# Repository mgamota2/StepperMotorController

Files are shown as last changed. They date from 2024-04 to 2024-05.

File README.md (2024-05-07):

# Stepper Motor Controller

## Purpose

This project was designed for the EV Concept Car team to enable autonomous steering. Stepper motors provide precise rotation and high torque, making them perfect for turning a steering wheel.

## Design

This project is a 48V isolated stepper motor controller which can be controlled over CAN or USB. The MCU used for this project is the STM32F103C8T6. The foundational part of the design are the 2 isolated H-Bridge circuits which drive the two coils in the stepper motor. The PCB files, gerbers, and BOM are included in this repo.

## Sources

Thank you to Nefastor Online for the COM over USB library for the STM32F1:
https://nefastor.com/microcontrollers/stm32/usb/stm32cube-usb-device-library/cdc-continued/
https://github.com/Nefastor-Online/STM32_VCP.git

## Report

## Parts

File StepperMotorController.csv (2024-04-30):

Source: | C:\Users\mggam\Documents\University of Illinois\EV Concept\StepperMotorController\StepperMotorController.kicad_sch
Date: | 2/20/2024 16:06
Tool: | Eeschema (6.0.7)
Generator: | C:\Program Files\KiCad\6.0\bin\scripting\plugins/bom_csv_grouped_by_value_with_fp.py
Component Count: | 132
Ref | Qnty | Value | Cmp name | Footprint | Description | Vendor
C1, C17, | 2 | 470uF | C_Polarized_US | Capacitor_THT:CP_Radial_D16.0mm_P7.50mm | Polarized capacitor, US symbol
C2, C3, C4, C6, C8, C9, C10, C13, C14, C18, C19, C21, C23, C24, C25, C26, C30, C31, | 18 | 0.1uF | C | Capacitor_SMD:C_0805_2012Metric | Unpolarized capacitor
C5, C7, C20, C22, | 4 | 1uF | C | Capacitor_SMD:C_0805_2012Metric | Unpolarized capacitor
C11, C12, C15, C16, C28, C29, C32, C33, | 8 | 4.7uF | C_Polarized_US | Capacitor_THT:CP_Radial_D8.0mm_P5.00mm | Polarized capacitor, US symbol
C27, C35, C36, | 3 | 4.7uF | C | Capacitor_SMD:C_0805_2012Metric | Unpolarized capacitor
C34, C37, C40, C47, | 4 | 10uF | C | Capacitor_SMD:C_0805_2012Metric | Unpolarized capacitor
C38, C39, | 2 | 10pF | C | Capacitor_SMD:C_0603_1608Metric | Unpolarized capacitor
C41, C42, C43, C44, C45, C46, | 6 | .1uF | C | Capacitor_SMD:C_0805_2012Metric | Unpolarized capacitor
CBOOT1, | 1 | 0.1uF | C | Capacitor_SMD:C_0805_2012Metric | Unpolarized capacitor
D1, | 1 | 82400102 | 82400102 | SamacSys_Parts:SOT95P280X145-6N | TVS Diode Array WE-TVS 2-Ch+VDD 5V SOT23 Wurth Elektronik 82400102, Uni-Directional TVS Diode Array Array, 7.7V, 6-Pin SOT-23
D2, D9, D10, D11, D12, D13, D14, | 7 | LED | LED | LED_SMD:LED_0603_1608Metric | Light emitting diode
D4, D5, D6, D7, | 4 | D | D | Diode_SMD:D_0805_2012Metric | Diode
D8, | 1 | D_Zener | D_Zener | Diode_SMD:D_0805_2012Metric | Zener diode
FB1, | 1 | FerriteBead | FerriteBead | Resistor_SMD:R_0805_2012Metric | Ferrite bead
IC1, IC2, IC4, IC5, | 4 | NCP51561BADWR2G | NCP51561BADWR2G | SamacSys_Parts:SOIC127P1030X265-16N | Isolated Gate Drivers 5 kVRMS Isolated Dual Channel 4.5/9 A Gate Driver 4.5/9A Isolated Dual Channel Gate Driver with 8V UVLO and ENABLE
IC3, | 1 | LMR51610XDBVR | LMR51610XDBVR | SamacSys_Parts:SOT95P280X145-6N | Switching Voltage Regulators SIMPLE SWITCHER&reg; 4.5-V to 65-V, 1-A synchronous buck converter with 25-&micro;A&nbsp;IQ 6-SOT-23 -40 to 150
IC6, | 1 | TC1264-3.3VDBTR | TC1264-3.3VDBTR | SamacSys_Parts:SOT230P700X180-4N | LDO Voltage Regulators 800mA Fixed Output
J1, | 1 | USB4085-GF-A_REVA4 | USB4085-GF-A_REVA4 | Connector_USB:USB_C_Receptacle_GCT_USB4085
J2, | 1 | 54602-908LF | 54602-908LF | SamacSys_Parts:54602908LF
J3, | 1 | PDS1-S24-S5-M-TR | PDS1-S24-S5-M-TR | SamacSys_Parts:PDS1S24S5MTR | Module DC-DC 24VIN 1-OUT 5V 0.2A 1W 5-Pin SMD Module T/R
J4, | 1 | Conn_02x05_Odd_Even | Conn_02x05_Odd_Even | Connector_PinSocket_2.54mm:PinSocket_2x05_P2.54mm_Vertical | Generic connector, double row, 02x05, odd/even pin numbering scheme (row 1 odd numbers, row 2 even numbers), script generated (kicad-library-utils/schlib/autogen/connector/)
J5, | 1 | 1984633 | 1984633 | Connector_Phoenix_GMSTB:PhoenixContact_GMSTBVA_2,5_4-G-7,62_1x04_P7.62mm_Vertical
J6, J7, | 2 | 7807 | 7807 | screw:CONN_7807_KEY
L1, | 1 | 82uH | L | Inductor_SMD:L_Bourns_SRR1260 | Inductor
Q1, Q2, Q3, Q4, Q5, Q6, Q7, Q8, | 8 | IRF740 | IRF740 | Package_TO_SOT_THT:TO-220-3_Vertical | 10A Id, 400V Vds, N-Channel Power MOSFET, 500mOhm Rds, TO-220AB
R1, R2, R21, R22, | 4 | 20k | R | Resistor_SMD:R_0805_2012Metric | Resistor
R3, R6, | 2 | 5.11k | R | Resistor_SMD:R_0805_2012Metric | Resistor
R4, R5, R12, R14, R15, R17, R23, R24, R31, R33, R34, R36, | 12 | 10k | R | Resistor_SMD:R_0805_2012Metric | Resistor
R7, | 1 | 120 | R | Resistor_SMD:R_0805_2012Metric | Resistor
R8, R9, R10, R11, R13, R16, R27, R28, R29, R30, R32, R35, | 12 | 10 | R | Resistor_SMD:R_0805_2012Metric | Resistor
R19, R38, R39, R40, R41, R42, R43, | 7 | 300 | R | Resistor_SMD:R_0805_2012Metric | Resistor
R20, | 1 | 1.5k | R | Resistor_SMD:R_0805_2012Metric | Resistor
R25, | 1 | 100k | R | Resistor_SMD:R_0805_2012Metric | Resistor
R26, | 1 | 3.48k | R | Resistor_SMD:R_0805_2012Metric | Resistor
R37, | 1 | 1K | R | Resistor_SMD:R_0805_2012Metric | Resistor
SW1, | 1 | 100SP1T1B4M2QE | 100SP1T1B4M2QE | 100S:100SP1T1_EWI
SW2, | 1 | 1825255-1 | 1825255-1 | switch182:SW3_1825255-1_TEC
SW3, | 1 | SW_Push | SW_Push | Button_Switch_SMD:SW_Push_SPST_NO_Alps_SKRK | Push button switch, generic, two pins
U1, | 1 | ISO1050DUB | ISO1050DUB | Package_SO:SOP-8_6.62x9.15mm_P2.54mm | Isolated CAN Transceiver, SOP-8
U2, | 1 | STM32F103C8Tx | STM32F103C8Tx | Package_QFP:LQFP-48_7x7mm_P0.5mm | ARM Cortex-M3 MCU, 64KB flash, 20KB RAM, 72MHz, 2-3.6V, 37 GPIO, LQFP-48
Y1, | 1 | Crystal_GND24 | Crystal_GND24 | SamacSys_Parts:ECS801033CHNTR3 | Four pin crystal, GND on pins 2 and 4

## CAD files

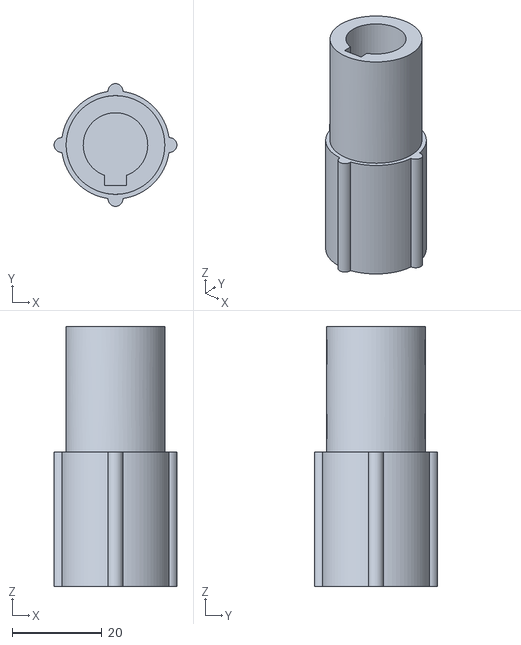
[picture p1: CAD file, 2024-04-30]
ApadterBody.stl
27.4 x 27.4 x 58.0

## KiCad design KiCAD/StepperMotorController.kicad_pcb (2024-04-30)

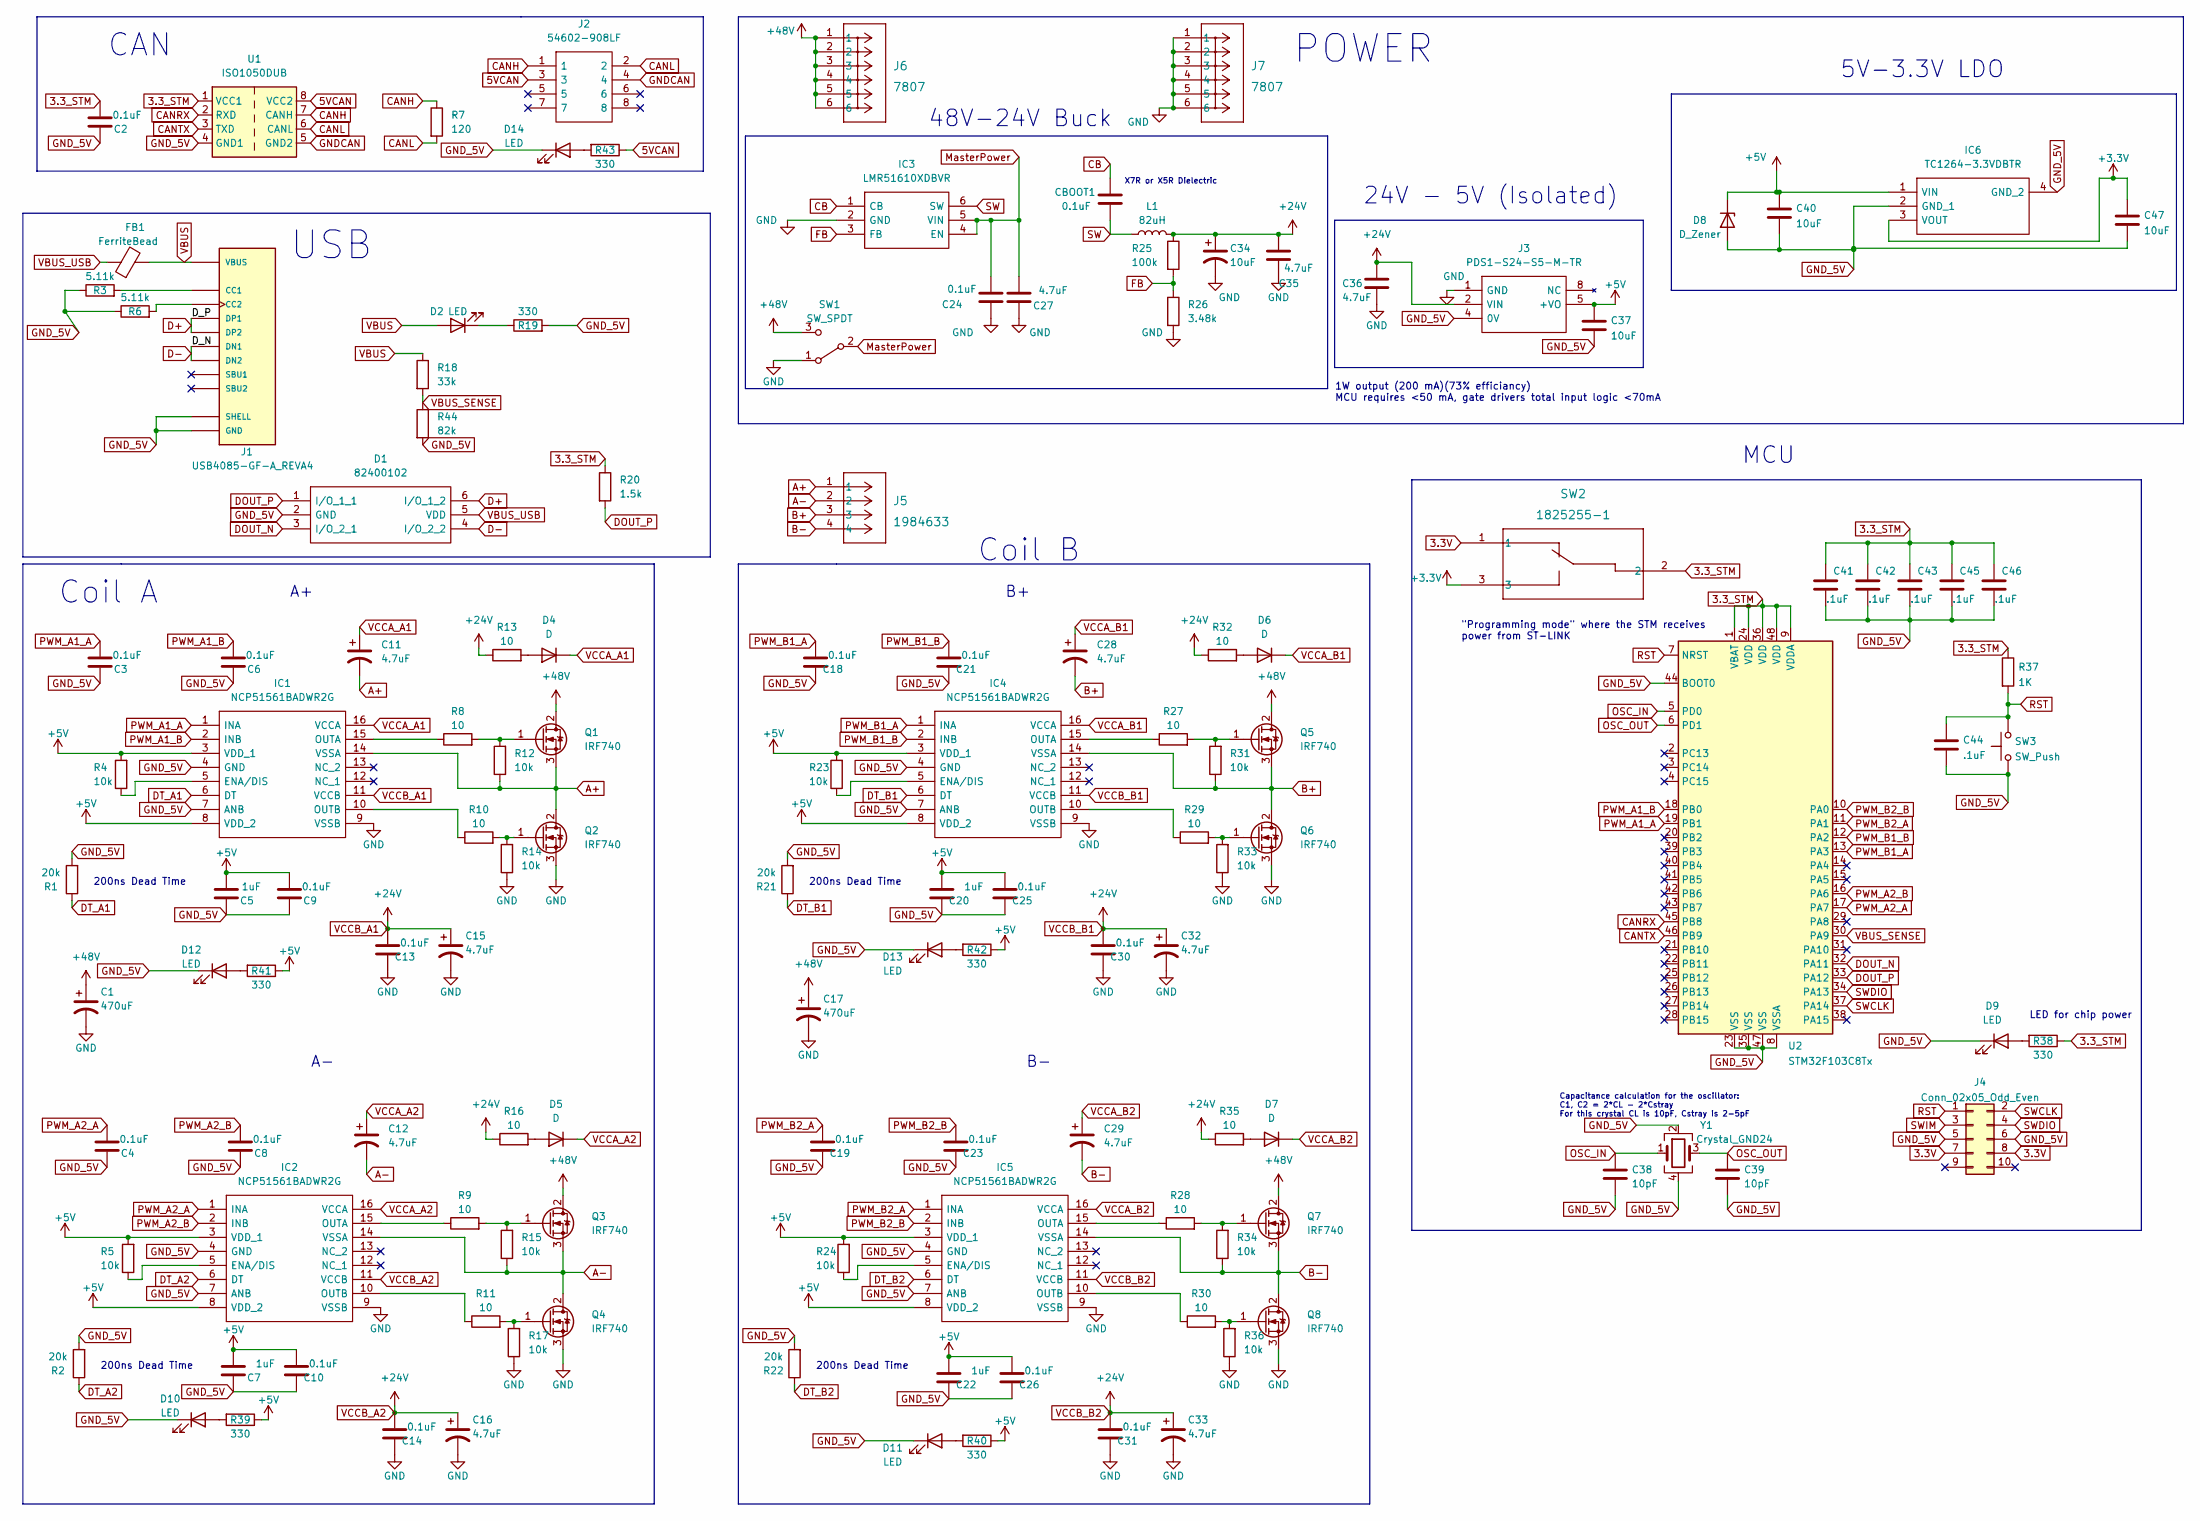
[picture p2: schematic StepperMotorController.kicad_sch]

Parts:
C1, C17: 470uF; CP_Radial_D16.0mm_P7.50mm
C2, C3, C4, C6, C8, C9, C10, C13, C14, C18, C19, C21, C23, C24, C25, C26, C30, C31: 0.1uF; C_0805_2012Metric
C5, C7, C20, C22: 1uF; C_0805_2012Metric
C11, C12, C15, C16, C28, C29, C32, C33: 4.7uF; CP_Radial_D8.0mm_P5.00mm
C27, C35, C36: 4.7uF; C_0805_2012Metric
C34, C37, C40, C47: 10uF; C_0805_2012Metric
C38, C39: 10pF; C_0603_1608Metric
C41, C42, C43, C44, C45, C46: .1uF; C_0805_2012Metric
CBOOT1: 0.1uF; C_0805_2012Metric
D1: 82400102; SOT95P280X145-6N; Mouser Part Number 710-82400102
D2, D9, D10, D11, D12, D13, D14: LED; LED_0603_1608Metric
D4, D5, D6, D7: D; D_0805_2012Metric
D8: D_Zener; D_0805_2012Metric
FB1: FerriteBead; R_0805_2012Metric
IC1, IC2, IC4, IC5: NCP51561BADWR2G; SOIC127P1030X265-16N; Manufacturer_Part_Number NCP51561BADWR2G
IC3: LMR51610XDBVR; SOT95P280X145-6N; Mouser Part Number 595-LMR51610XDBVR
IC6: TC1264-3.3VDBTR; SOT230P700X180-4N; Mouser Part Number 579-TC1264-3.3VDBTR
J1: USB4085-GF-A_REVA4; USB_C_Receptacle_GCT_USB4085; PARTREV A4
J2: 54602-908LF; 54602908LF; Mouser Part Number 649-54602-908LF
J3: PDS1-S24-S5-M-TR; PDS1S24S5MTR; Mouser Part Number 490-PDS1-S24-S5-M-TR
J4: Conn_02x05_Odd_Even; PinSocket_2x05_P2.54mm_Vertical
J5: 1984633; PhoenixContact_GMSTBVA_2,5_4-G-7,62_1x04_P7.62mm_Vertical
J6, J7: 7807; CONN_7807_KEY
L1: 82uH; L_Bourns_SRR1260
Q1, Q2, Q3, Q4, Q5, Q6, Q7, Q8: IRF740; TO-220-3_Vertical
R1, R2, R21, R22: 20k; R_0805_2012Metric
R3, R6: 5.11k; R_0805_2012Metric
R4, R5, R12, R14, R15, R17, R23, R24, R31, R33, R34, R36: 10k; R_0805_2012Metric
R7: 120; R_0805_2012Metric
R8, R9, R10, R11, R13, R16, R27, R28, R29, R30, R32, R35: 10; R_0805_2012Metric
R18: 33k; R_0805_2012Metric
R19, R38, R39, R40, R41, R42, R43: 330; R_0805_2012Metric
R20: 1.5k; R_0805_2012Metric
R25: 100k; R_0805_2012Metric
R26: 3.48k; R_0805_2012Metric
R37: 1K; R_0805_2012Metric
R44: 82k; R_0805_2012Metric
SW1: SW_SPDT; 100SP1T1_EWI
SW2: 1825255-1; SW3_1825255-1_TEC
SW3: SW_Push; SW_Push_SPST_NO_Alps_SKRK
U1: ISO1050DUB; SOP-8_6.62x9.15mm_P2.54mm
U2: STM32F103C8Tx; LQFP-48_7x7mm_P0.5mm
Y1: Crystal_GND24; ECS801033CHNTR3

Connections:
3.3V: J4.7, J4.8, SW2.1
3.3_STM: C2.2, C41.1, C42.1, C43.1, C45.1, C46.1, R20.1, R37.1, R38.1, SW2.2, U1.1 (VCC1), U2.1 (VBAT), U2.9 (VDDA), U2.24 (VDD), U2.36 (VDD), U2.48 (VDD)
5VCAN: J2.3, R43.1, U1.8 (VCC2)
+3.3V: C47.1, IC6.3 (VOUT), SW2.3
+5V: C5.2, C7.2, C9.2, C10.2, C20.2, C22.2, C25.2, C26.2, C37.1, C40.1, D8.1 (K), IC1.3 (VDD_1), IC1.8 (VDD_2), IC2.3 (VDD_1), IC2.8 (VDD_2), IC4.3 (VDD_1), IC4.8 (VDD_2), IC5.3 (VDD_1), IC5.8 (VDD_2), IC6.1 (VIN), J3.5 (+VO), R4.2, R5.2, R23.2, R24.2, R39.1, R40.1, R41.1, R42.1
+48V: C1.1, C17.1, J6.1, J6.2, J6.3, J6.4, J6.5, J6.6, Q1.2 (D), Q3.2 (D), Q5.2 (D), Q7.2 (D), SW1.3 (C)
A+: C11.2, IC1.14 (VSSA), J5.1, Q1.3 (S), Q2.2 (D), R12.1
A-: C12.2, IC2.14 (VSSA), J5.2, Q3.3 (S), Q4.2 (D), R15.1
B+: C28.2, IC4.14 (VSSA), J5.3, Q5.3 (S), Q6.2 (D), R31.1
B-: C29.2, IC5.14 (VSSA), J5.4, Q7.3 (S), Q8.2 (D), R34.1
CANH: J2.1, R7.1, U1.7 (CANH)
CANL: J2.2, R7.2, U1.6 (CANL)
CANRX: U1.2 (RXD), U2.45 (PB8)
CANTX: U1.3 (TXD), U2.46 (PB9)
CB: CBOOT1.1, IC3.1 (CB)
D+: D1.6 (I/O_1_2), J1.A6 (DP1), J1.B6 (DP2)
D-: D1.4 (I/O_2_2), J1.A7 (DN1), J1.B7 (DN2)
DOUT_N: D1.3 (I/O_2_1), U2.32 (PA11)
DOUT_P: D1.1 (I/O_1_1), R20.2, U2.33 (PA12)
DT_A1: IC1.6 (DT), R1.1
DT_A2: IC2.6 (DT), R2.1
DT_B1: IC4.6 (DT), R21.1
DT_B2: IC5.6 (DT), R22.1
FB: IC3.3 (FB), R25.2, R26.1
GND: C1.2, C13.1, C14.1, C15.2, C16.2, C17.2, C24.1, C27.1, C30.1, C31.1, C32.2, C33.2, C34.2, C35.1, C36.2, IC1.9 (VSSB), IC2.9 (VSSB), IC3.2 (GND), IC4.9 (VSSB), IC5.9 (VSSB), J3.1 (GND), J7.1, J7.2, J7.3, J7.4, J7.5, J7.6, Q2.3 (S), Q4.3 (S), Q6.3 (S), Q8.3 (S), R14.1, R17.1, R26.2, R33.1, R36.1, SW1.1 (A)
GNDCAN: J2.4, U1.5 (GND2)
GND_5V: C2.1, C3.1, C4.1, C5.1, C6.1, C7.1, C8.1, C9.1, C10.1, C18.1, C19.1, C20.1, C21.1, C22.1, C23.1, C25.1, C26.1, C37.2, C38.2, C39.2, C40.2, C41.2, C42.2, C43.2, C44.2, C45.2, C46.2, C47.2, D1.2 (GND), D8.2 (A), D9.1 (K), D10.1 (K), D11.1 (K), D12.1 (K), D13.1 (K), D14.1 (K), IC1.4 (GND), IC1.7 (ANB), IC2.4 (GND), IC2.7 (ANB), IC4.4 (GND), IC4.7 (ANB), IC5.4 (GND), IC5.7 (ANB), IC6.2 (GND_1), IC6.4 (GND_2), J1.A1 (GND), J1.A12 (GND), J1.B1 (GND), J1.B12 (GND), J1.P1 (SHELL), J1.P2 (SHELL), J1.P3 (SHELL), J1.P4 (SHELL), J3.4 (0V), J4.5, J4.6, R1.2, R2.2, R3.1, R6.1, R19.2, R21.2, R22.2, R44.2, SW3.1, U1.4 (GND1), U2.8 (VSSA), U2.23 (VSS), U2.35 (VSS), U2.44 (BOOT0), U2.47 (VSS), Y1.2, Y1.4; also elsewhere on the board
MasterPower: C24.2, C27.2, IC3.4 (EN), IC3.5 (VIN), SW1.2 (B)
unnamed 28: D2.1 (K), R19.1; also elsewhere on the board
unnamed: D4.2 (A), R13.2
unnamed: D5.2 (A), R16.2
unnamed: D6.2 (A), R32.2
unnamed: D7.2 (A), R35.2
unnamed 33: D9.2 (A), R38.2; also elsewhere on the board
unnamed: D10.2 (A), R39.2
unnamed: D11.2 (A), R40.2
unnamed: D12.2 (A), R41.2
unnamed: D13.2 (A), R42.2
unnamed: D14.2 (A), R43.2
unnamed: IC1.5 (ENA/DIS), R4.1
unnamed: IC1.10 (OUTB), R10.1
unnamed: IC1.15 (OUTA), R8.1
unnamed: IC2.5 (ENA/DIS), R5.1
unnamed: IC2.10 (OUTB), R11.1
unnamed: IC2.15 (OUTA), R9.1
unnamed: IC4.5 (ENA/DIS), R23.1
unnamed: IC4.10 (OUTB), R29.1
unnamed: IC4.15 (OUTA), R27.1
unnamed: IC5.5 (ENA/DIS), R24.1
unnamed: IC5.10 (OUTB), R30.1
unnamed: IC5.15 (OUTA), R28.1
unnamed: J1.A5 (CC1), R3.2
unnamed: J1.B5 (CC2), R6.2
unnamed: Q1.1 (G), R8.2, R12.2
unnamed: Q2.1 (G), R10.2, R14.2
unnamed: Q3.1 (G), R9.2, R15.2
unnamed: Q4.1 (G), R11.2, R17.2
unnamed: Q5.1 (G), R27.2, R31.2
unnamed: Q6.1 (G), R29.2, R33.2
unnamed: Q7.1 (G), R28.2, R34.2
unnamed: Q8.1 (G), R30.2, R36.2
OSC_IN: C38.1, U2.5 (PD0), Y1.1
OSC_OUT: C39.1, U2.6 (PD1), Y1.3
PWM_A1_A: C3.2, IC1.1 (INA), U2.19 (PB1)
PWM_A1_B: C6.2, IC1.2 (INB), U2.18 (PB0)
PWM_A2_A: C4.2, IC2.1 (INA), U2.17 (PA7)
PWM_A2_B: C8.2, IC2.2 (INB), U2.16 (PA6)
PWM_B1_A: C18.2, IC4.1 (INA), U2.13 (PA3)
PWM_B1_B: C21.2, IC4.2 (INB), U2.12 (PA2)
PWM_B2_A: C19.2, IC5.1 (INA), U2.11 (PA1)
PWM_B2_B: C23.2, IC5.2 (INB), U2.10 (PA0)
RST: C44.1, J4.1, R37.2, SW3.2, U2.7 (NRST)
SW: CBOOT1.2, IC3.6 (SW), L1.1
SWCLK: J4.2, U2.37 (PA14)
SWDIO: J4.4, U2.34 (PA13)
SWIM: J4.3
VBUS: D2.2 (A), FB1.2, J1.A4 (VBUS), J1.A9 (VBUS), J1.B4 (VBUS), J1.B9 (VBUS), R18.1; also elsewhere on the board
VBUS_SENSE: R18.2, R44.1, U2.30 (PA9)
VBUS_USB: D1.5 (VDD), FB1.1
VCCA_A1: C11.1, D4.1 (K), IC1.16 (VCCA)
VCCA_A2: C12.1, D5.1 (K), IC2.16 (VCCA)
VCCA_B1: C28.1, D6.1 (K), IC4.16 (VCCA)
VCCA_B2: C29.1, D7.1 (K), IC5.16 (VCCA)
VCCB_A1: C13.2, C14.2, C15.1, C16.1, C30.2, C31.2, C32.1, C33.1, C34.1, C35.2, C36.1, IC1.11 (VCCB), IC2.11 (VCCB), IC4.11 (VCCB), IC5.11 (VCCB), J3.2 (VIN), L1.2, R13.1, R16.1, R25.1, R32.1, R35.1

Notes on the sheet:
X7R or X5R Dielectric
Capacitance calculation for the oscillator: C1, C2 = 2*CL - 2*Cstray For this crystal CL is 10pF, Cstray is 2-5pF
Coil B
1W output (200 mA)(73% efficiancy) MCU requires <50 mA, gate drivers total input logic <70mA
USB
MCU
200ns Dead Time
LED for chip power
CAN
24V - 5V (Isolated)
48V-24V Buck
Coil A
5V-3.3V LDO
POWER
"Programming mode" where the STM receives power from ST-LINK

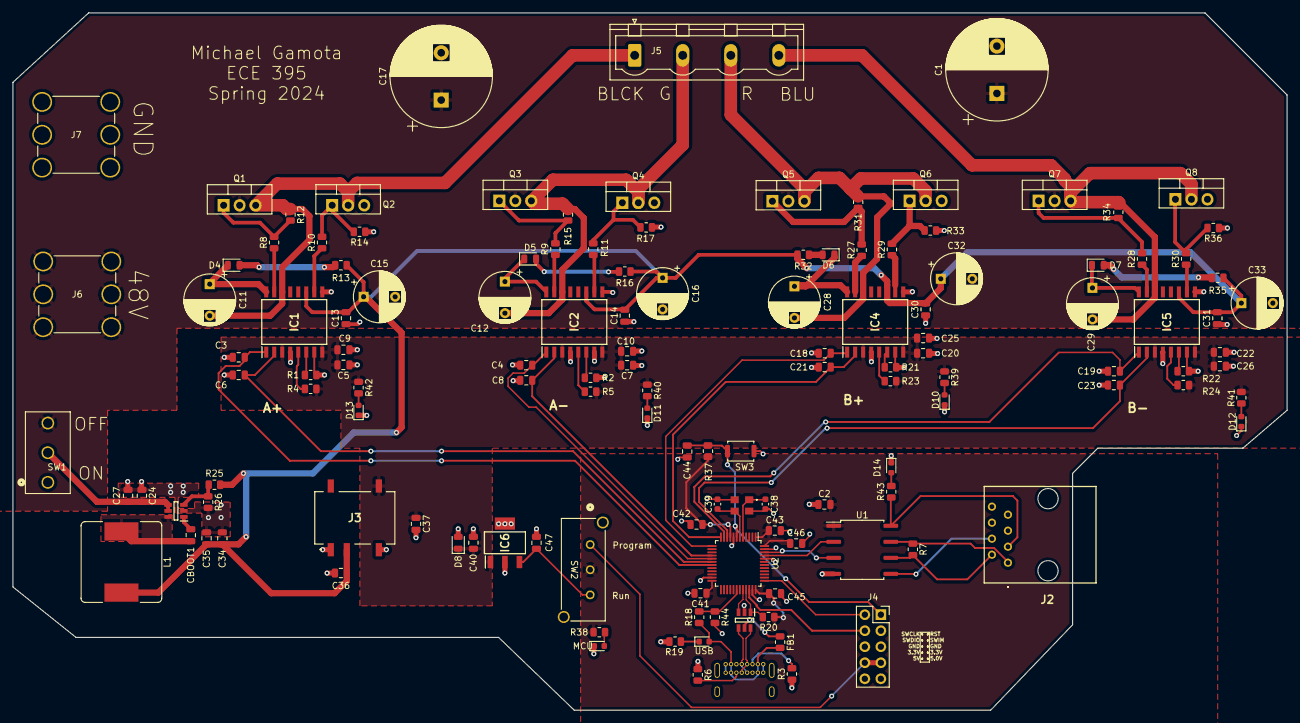
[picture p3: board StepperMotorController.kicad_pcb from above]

Board: 2 copper layers, 202.0 x 110.6 mm, 134 parts (1 on the bottom side), 83 nets.

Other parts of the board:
MCU: LED; LED_0603_1608Metric
USB: LED; LED_0603_1608Metric

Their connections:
GND_5V: MCU.1 (K); also elsewhere on the board
unnamed 28: USB.1 (K); also elsewhere on the board
unnamed 33: MCU.2 (A); also elsewhere on the board
VBUS: USB.2 (A); also elsewhere on the board

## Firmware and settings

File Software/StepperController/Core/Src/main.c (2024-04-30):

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
/* Includes ------------------------------------------------------------------*/
#include "main.h"
#include "usb_device.h"

/* USER CODE BEGIN Includes */
#include "string.h"
#include "usbd_cdc_if.h"
/* USER CODE END Includes */

/* USER CODE BEGIN PD */
//This value is so we don't burn out the stepper with current (V=IR)

/* USER CODE END PD */

CAN_HandleTypeDef hcan;

TIM_HandleTypeDef htim2;
TIM_HandleTypeDef htim3;

/* USER CODE BEGIN PV */
const uint16_t DUTY_CYCLE=1800;
uint8_t phase=1;
signed int position = 0;
/* USER CODE END PV */

void SystemClock_Config(void);
static void MX_GPIO_Init(void);
static void MX_CAN_Init(void);
static void MX_TIM2_Init(void);
static void MX_TIM3_Init(void);
/* USER CODE BEGIN PFP */
void set_pwm(uint8_t coil, uint8_t channel, uint16_t duty_cycle);
void user_pwm_init();
void stop_motor();
void set_phase(uint8_t this_phase);
void fs_right();
void fs_left();
void fs_right_deg(uint16_t degrees);
void fs_left_deg(uint16_t degrees);
void zero_pos();
/* USER CODE END PFP */

/**
  * @brief  The application entry point.
  * @retval int
  */
int main(void)
{
  /* MCU Configuration--------------------------------------------------------*/

  /* Reset of all peripherals, Initializes the Flash interface and the Systick. */
  HAL_Init();

  /* Configure the system clock */
  SystemClock_Config();

  /* Initialize all configured peripherals */
  MX_GPIO_Init();
  MX_CAN_Init();
  MX_TIM2_Init();
  MX_TIM3_Init();
  MX_USB_DEVICE_Init();
  /* USER CODE BEGIN 2 */
  //Set up all PWM timers and set all duty cycles to 0
  user_pwm_init();
  stop_motor();


//  vcp_init(); //https://nefastor.com/microcontrollers/stm32/usb/stm32cube-usb-device-library/cdc-continued/
  uint8_t buf[1000];
  uint8_t done[1]={0xFF};
  int len=0;
  /* USER CODE END 2 */

  /* Infinite loop */
  /* USER CODE BEGIN WHILE */
  while (1)
  {

//	 CDC_Transmit_FS((uint8_t*)buf, strlen(buf));
//	 len = 0;
//	 while (len<=0){
//		 len = vcp_recv (buf, 1000);  // Read up to 1000 bytes
//		 if (buf[0]==0){
//			 fs_right_deg(buf[1]);
//		 }
//		 else if (buf[0]==1){
//			 fs_right_deg(buf[1]);
//		 }
//	  	 len = vcp_send (done, sizeof(char));
//
//	 }
	 HAL_Delay(500);
	 fs_right();
//	 HAL_Delay(500);
//	 fs_right_deg(90);
//	 HAL_Delay(500);
//	 zero_pos();
//	 HAL_Delay(500);
//	 fs_left_deg(90);
//	 HAL_Delay(500);
//	 fs_right_deg(270);
//	 HAL_Delay(500);
//	 fs_right_deg(90);
//	 HAL_Delay(500);
//	 zero_pos();
//	 HAL_Delay(5000);

    /* USER CODE END WHILE */

    /* USER CODE BEGIN 3 */
  }
  /* USER CODE END 3 */
}

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
/* USER CODE BEGIN 4 */
//Set individual channel duty cycle
void set_pwm(uint8_t coil, uint8_t channel, uint16_t duty_cycle){
	if (coil==1 && channel==1){
		TIM3->CCR1=duty_cycle;
	}
	else if (coil==1 && channel==2){
		TIM3->CCR2=duty_cycle;
	}
	else if (coil==1 && channel==3){
		TIM3->CCR3=duty_cycle;
	}
	else if (coil==1 && channel==4){
		TIM3->CCR4=duty_cycle;
	}
	else if (coil==2 && channel==1){
		TIM2->CCR1=duty_cycle;
	}
	else if (coil==2 && channel==2){
		TIM2->CCR2=duty_cycle;
	}
	else if (coil==2 && channel==3){
		TIM2->CCR3=duty_cycle;
	}
	else if (coil==2 && channel==4){
		TIM2->CCR4=duty_cycle;
	}

}
//Start timers for all channels
void user_pwm_init(){
	//Coil A
	HAL_TIM_PWM_Start(&htim3, TIM_CHANNEL_1);
	HAL_TIM_PWM_Start(&htim3, TIM_CHANNEL_2);
	HAL_TIM_PWM_Start(&htim3, TIM_CHANNEL_3);
	HAL_TIM_PWM_Start(&htim3, TIM_CHANNEL_4);
	//Coil B
	HAL_TIM_PWM_Start(&htim2, TIM_CHANNEL_1);
	HAL_TIM_PWM_Start(&htim2, TIM_CHANNEL_2);
	HAL_TIM_PWM_Start(&htim2, TIM_CHANNEL_3);
	HAL_TIM_PWM_Start(&htim2, TIM_CHANNEL_4);
}
//Set all duty cycles to 0
void stop_motor(){
	for (uint8_t coil=2;coil>0;coil--){
		  for (uint8_t ch=4;ch>0;ch--){
			  set_pwm(coil, ch, 0);
		 }
	}
}

void set_phase(uint8_t this_phase){
	stop_motor();
	if (this_phase==1){
		set_pwm(1, 1, DUTY_CYCLE);
		set_pwm(2, 1, DUTY_CYCLE);

		set_pwm(1, 4, DUTY_CYCLE);
		set_pwm(2, 4, DUTY_CYCLE);
	}
	else if (this_phase==2){
		set_pwm(1, 3, DUTY_CYCLE);
		set_pwm(2, 1, DUTY_CYCLE);
		set_pwm(2, 4, DUTY_CYCLE);
		set_pwm(1, 2, DUTY_CYCLE);
	}
	else if(this_phase==3){
		set_pwm(1, 3, DUTY_CYCLE);
		set_pwm(2, 3, DUTY_CYCLE);
		set_pwm(2, 2, DUTY_CYCLE);
		set_pwm(1, 2, DUTY_CYCLE);
	}
	else if (this_phase==4){
		set_pwm(1, 1, DUTY_CYCLE);
		set_pwm(2, 3, DUTY_CYCLE);
		set_pwm(1, 4, DUTY_CYCLE);
		set_pwm(2, 2, DUTY_CYCLE);

	}
	phase=this_phase;
}

//Turn motor right (A1,A4)(B1, B4) -> (A2,A3)(B1, B4) -> (A2,A3)(B2, B3) -> (A1,A4)(B2, B3)
void fs_right(){
	for (int i=4; i>0; i--){
		phase=phase%4;
		set_phase(++phase); //Increment phase

		//Hardware delay 8 MHz=0.12 uS per tick, 4300 ticks = 516us
		for (volatile uint32_t i =0; i<4300;i++);
	}
}
//Turn motor left (A1,A4)(B2, B3) -> (A2,A3)(B2, B3) -> (A2,A3)(B1, B4)-> (A1,A4)(B1, B4)
void fs_left(){
	for (int i=4; i>0; i--){
		if (phase<=1){
			set_phase(4); //Loop back to 4 after 1
		}
		else{
			set_phase(--phase); //Decrement phase
		}

		//Hardware delay 8 MHz=0.12 uS per tick, 4300 ticks = 516us
		for (volatile uint32_t i =0; i<4300;i++);
	}
}

void fs_right_deg(uint16_t degrees){
	uint16_t steps = (degrees/0.72); //10:1 gearbox so 0.18 degrees per step, fs_right and fs_left do 4 steps
	for (int i=steps; i>0; i--){
		fs_right();
//		for (volatile uint16_t i=0; i!=0x9C4; i++); //Hardware delay
	}
	position += degrees;
	stop_motor();

}

void fs_left_deg(uint16_t degrees){
	uint16_t steps = (degrees/0.72); //10:1 gearbox so 0.18 degrees per step, fs_right and fs_left do 4 steps
	for (int i=steps; i>0; i--){
		fs_left();
//		for (volatile uint16_t i=0; i!=0x9C4; i++); //Hardware delay
	}
	position -= degrees;
	stop_motor();


}

void zero_pos(){
	if (position>0){
		fs_left_deg(position);
	}
	else{
		fs_right_deg(position);
	}
}

/* USER CODE END 4 */
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


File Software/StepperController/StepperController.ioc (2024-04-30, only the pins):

Mcu.UserName=STM32F103C8Tx
PA0-WKUP.GPIO_Label=PWM_B2B
PA0-WKUP.Signal=S_TIM2_CH1_ETR
PA1.GPIO_Label=PWM_B2A
PA1.Signal=S_TIM2_CH2
PA11.Signal=USB_DM
PA12.Signal=USB_DP
PA13.Signal=SYS_JTMS-SWDIO
PA14.Signal=SYS_JTCK-SWCLK
PA2.GPIO_Label=PWM_B1B
PA2.Signal=S_TIM2_CH3
PA3.GPIO_Label=PWM_B1A
PA3.Signal=S_TIM2_CH4
PA6.GPIO_Label=PWM_A2B
PA6.Signal=S_TIM3_CH1
PA7.GPIO_Label=PWM_A2A
PA7.Signal=S_TIM3_CH2
PB0.GPIO_Label=PWM_A1B
PB0.Signal=S_TIM3_CH3
PB1.GPIO_Label=PWM_A1A
PB1.Signal=S_TIM3_CH4
PB8.Signal=CAN_RX
PB9.Signal=CAN_TX
PD0-OSC_IN.Signal=RCC_OSC_IN
PD1-OSC_OUT.Signal=RCC_OSC_OUT

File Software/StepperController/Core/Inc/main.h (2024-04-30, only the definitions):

#define PWM_B2B_Pin GPIO_PIN_0
#define PWM_B2B_GPIO_Port GPIOA
#define PWM_B2A_Pin GPIO_PIN_1
#define PWM_B2A_GPIO_Port GPIOA
#define PWM_B1B_Pin GPIO_PIN_2
#define PWM_B1B_GPIO_Port GPIOA
#define PWM_B1A_Pin GPIO_PIN_3
#define PWM_B1A_GPIO_Port GPIOA
#define PWM_A2B_Pin GPIO_PIN_6
#define PWM_A2B_GPIO_Port GPIOA
#define PWM_A2A_Pin GPIO_PIN_7
#define PWM_A2A_GPIO_Port GPIOA
#define PWM_A1B_Pin GPIO_PIN_0
#define PWM_A1B_GPIO_Port GPIOB
#define PWM_A1A_Pin GPIO_PIN_1
#define PWM_A1A_GPIO_Port GPIOB

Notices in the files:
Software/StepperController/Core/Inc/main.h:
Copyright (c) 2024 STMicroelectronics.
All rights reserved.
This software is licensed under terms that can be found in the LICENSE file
